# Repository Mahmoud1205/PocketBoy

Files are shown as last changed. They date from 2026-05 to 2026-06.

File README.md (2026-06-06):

# PocketBoy

The PocketBoy is a small handheld console made completely from scratch with a custom PCB and enclosure. The PocketBoy is small enough to fit in a pocket but has a 1000mAh battery for long gaming sessions. The PocketBoy has 8 buttons and a 128x64 monochrome OLED display, it also has a buzzer and a vibration motor.

The PocketBoy is made so you can kill time offline anywhere you are. It is very small (approximately 8x5cm) to easily fit in a pocket and has a strong battery which can be easily replaced. It also has a passive buzzer and vibration motor for extra immersion.

This is a project for the Hack Club Fallout program.

## How to use the PocketBoy

## Fabrication and Assembly Info
- Design files can be found in `/Design/Hardware`.
- Shapr3D link: https://app.shapr3d.com/p/6ae6ebff-efae-4364-8fd7-c0a60253d18e
- Some prototype code can be found in `/Design/Software`. More software will be added in the future.
- M2x20mm screws are used to hold the two enclosure parts together. Please thread them manually after printing the enclosure.
- Please ensure to solder the USB connector accurately so it can fit in the enclosure.
- Please print the design so that the two enclosure parts and all of the buttons are separate from each other.
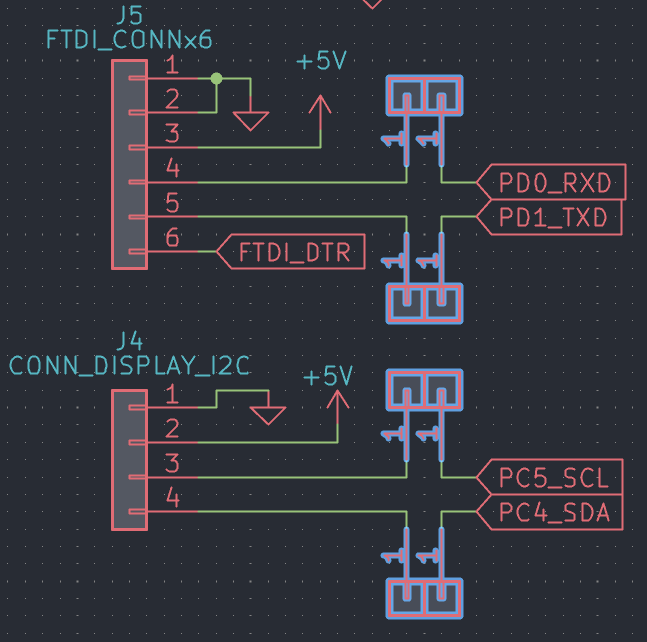
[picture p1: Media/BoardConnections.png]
Board Connections
- The PCB is split into two PCBs, they are connected together using wires after printing both of them. The board connection wires are drawn in the schematic as two 01x01 connectors placed next to each other as in the image below. 
- When soldering the power switch on the bottom PCB, please make sure that its wires come out of the top PCB so the switch can be placed in its position securely.
- After all parts are fabricated, you assemble the console this way: first place the battery at the bottom of the enclosure, then place the bottom PCB above the battery, it should float above the battery because the USB connecter will raise it. Then put the power switch in its hole and secure it in its place. Then place the buttons on the top part of the enclosure and then align the top PCB to be placed above the bottom PCB with a distance enough to keep the buttons stable above the top PCB. Then put the display in the display hole on the top part of the enclosure. Then place both parts of the enclosure on top of each other and hold them together using M2x20mm screws.
- The board can be programmed using an FTDI connector on the top PCB.

## Notes for Fallout reviewers.
As of now there is only a very simple FlappyBird game but I will make more games when the console is built.

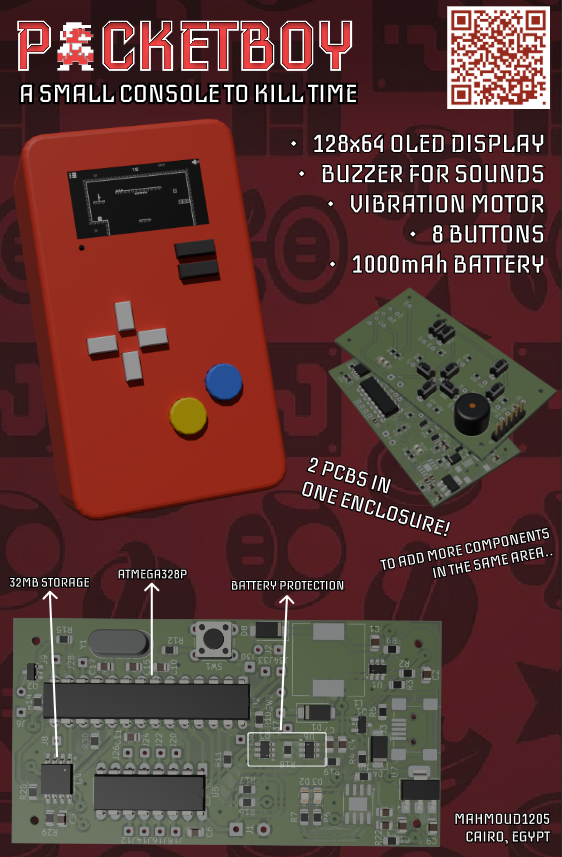
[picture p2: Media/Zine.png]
Zine

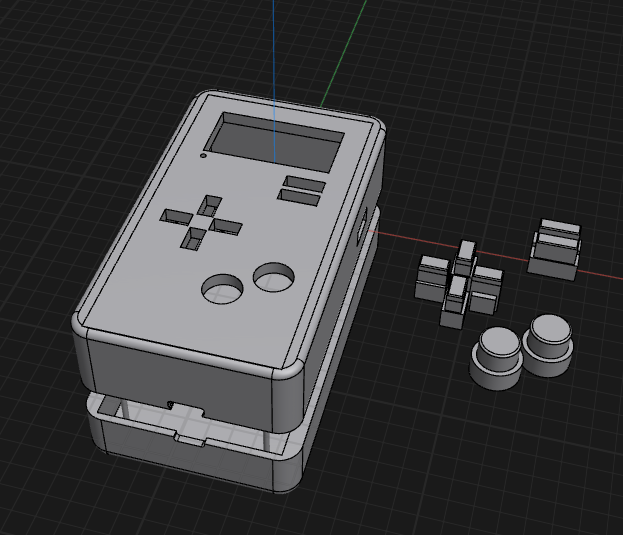
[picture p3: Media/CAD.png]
CAD

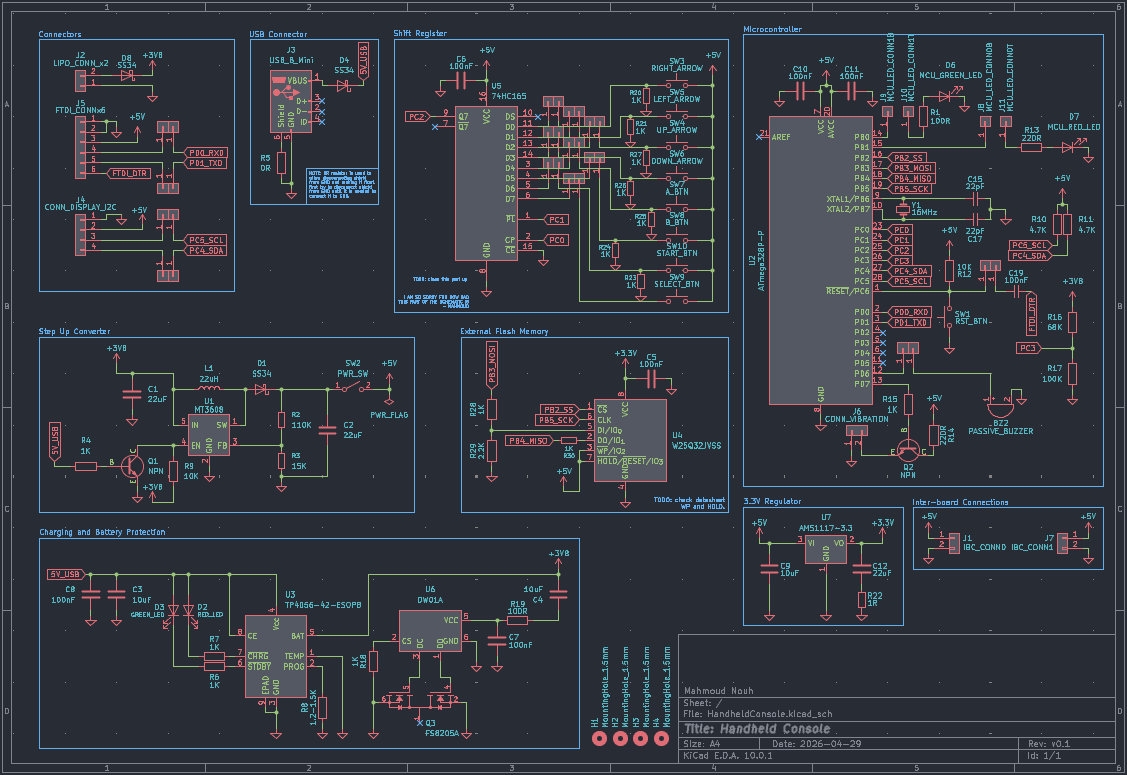
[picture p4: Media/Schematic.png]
Schematic

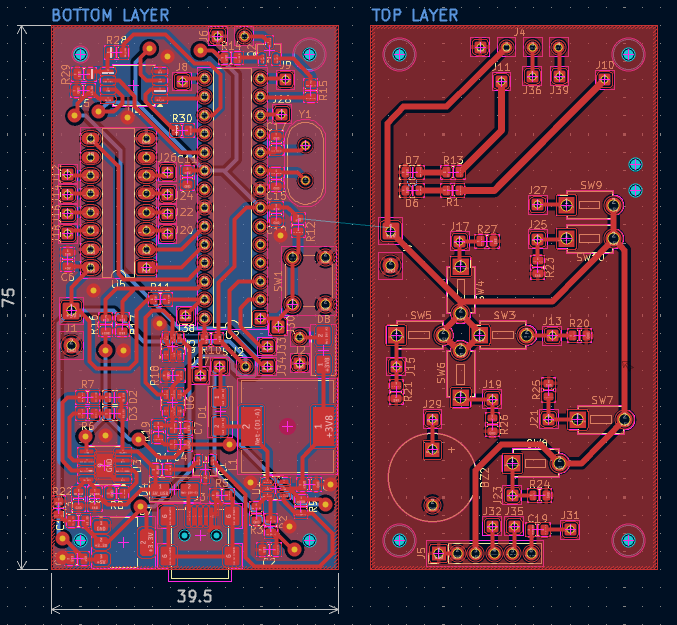
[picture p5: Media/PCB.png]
PCB


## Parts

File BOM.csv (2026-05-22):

 | Sourced | Placed | References | Value | Footprint | Quantity | Link
1 |  |  | C5, C6, C7, C8, C10, C11, C19 | 100nF | C_0805_2012Metric | 7 | https://lampatronics.com/product/smd-multilayer-ceramic-capacitor-0805-2012-104-100nf-50v-1pcs-2
2 |  |  | C1, C2, C12 | 22uF | C_0805_2012Metric | 3 | https://lampatronics.com/product/smd-multilayer-ceramic-capacitor-0805-22uf-6-3v-1pcs
3 |  |  | C3, C4, C9 | 10uF | C_0805_2012Metric | 3 | https://lampatronics.com/product/smd-multilayer-ceramic-capacitor-0805-10610uf-16v-1pcs
4 |  |  | C15, C17 | 22pF | C_0805_2012Metric | 2 | https://lampatronics.com/product/smd-multilayer-ceramic-capacitor-0805-2012-104-100nf-50v-1pcs
5 |  |  | R4, R6, R7, R15, R18, R20, R21, R23, R24, R25, R26, R27, R28, R30 | 1K | R_0805_2012Metric | 14 | https://lampatronics.com/product/smd-resistor-1kohm-102-0805-10pcs
6 |  |  | R1, R19 | 100R | R_0805_2012Metric | 2 | https://lampatronics.com/product/smd-resistor-100ohm-101-0805-10pcs
7 |  |  | R9, R12 | 10K | R_0805_2012Metric | 2 | https://lampatronics.com/product/smd-resistor-10kohm-103-0805-10pcs
8 |  |  | R10, R11 | 4.7K | R_0805_2012Metric | 2 | https://lampatronics.com/product/smd-resistor-4-7kohm-472-0805-10pcs
9 |  |  | R13, R14 | 220R | R_0805_2012Metric | 2 | https://lampatronics.com/product/smd-resistor-220ohm-221-0805-10pcs
10 |  |  | R2 | 110K | R_0805_2012Metric | 1 | https://makerselectronics.com/product/chip-resistor-smd-110k%cf%89-%c2%b11-0-125w-%c2%b1100ppm-%e2%84%83-0805/
11 |  |  | R3 | 15K | R_0805_2012Metric | 1 | https://makerselectronics.com/product/chip-resistor-smd-15k%CF%89-%C2%B11-0-125w-%C2%B1100ppm-%E2%84%83-0805/
12 |  |  | R5 | 0R | R_0805_2012Metric | 1 | https://makerselectronics.com/product/chip-resistor-smd-0%CF%89-%C2%B11-0-125w-0805/
13 |  |  | R8 | 1.2-1.5K | R_0805_2012Metric | 1 | https://lampatronics.com/product/smd-resistor-1-2kohm-122-0805-10pcs
14 |  |  | R16 | 68K | R_0805_2012Metric | 1 | https://makerselectronics.com/product/chip-resistor-smd-68k%CF%89-%C2%B11-0-125w-%C2%B1100ppm-%E2%84%83-0805/
15 |  |  | R17 | 100K | R_0805_2012Metric | 1 | https://lampatronics.com/product/smd-resistor-100kohm-104-0805-10pcs
16 |  |  | R22 | 1R | R_0805_2012Metric | 1 | https://lampatronics.com/product/smd-resistor-1ohm-1r0-0805-10pcs
17 |  |  | R29 | 2.2K | R_0805_2012Metric | 1 | https://lampatronics.com/product/smd-resistor-2-2kohm-222-0805-10pcs
18 |  |  | L1 | 22uH | L_12x12mm_H4.5mm | 1 | https://makerselectronics.com/product/cdrh124-smd-pwr-fixed-inductors-22u/
19 |  |  | D1, D4, D8 | SS34 | D_SMA | 3 | https://lampatronics.com/product/smd-schottky-diode-ss34-1n5822-3a-40v
20 |  |  | D2 | RED_LED | LED_0805_2012Metric | 1 | https://lampatronics.com/product/smd-led-0805-red-10pcs
21 |  |  | D3 | GREEN_LED | LED_0805_2012Metric | 1 | https://lampatronics.com/product/smd-led-0805-green-10pcs
22 |  |  | D6 | MCU_GREEN_LED | LED_0805_2012Metric | 1 | https://lampatronics.com/product/smd-led-0805-green-10pcs
23 |  |  | D7 | MCU_RED_LED | LED_0805_2012Metric | 1 | https://lampatronics.com/product/smd-led-0805-red-10pcs
24 |  |  | U1 | MT3608 | SOT-23-6 | 1 | https://makerselectronics.com/product/mt3608-boost-converter-type-28v-2v24v-sot-23-6-dc-dc-converter/
25 |  |  | U2 | ATmega328P-P | DIP-28_W7.62mm | 1 | https://lampatronics.com/product/atmega328-p-au-smd
26 |  |  | U3 | TP4056-42-ESOP8 | SOIC-8-1EP_3.9x4.9mm_P1.27mm_EP2.41x3.3mm | 1 | https://makerselectronics.com/product/smd-tp4056-battery-management-sop-8/
27 |  |  | U4 | W25Q32JVSS | SOIC-8_5.3x5.3mm_P1.27mm | 1 | https://makerselectronics.com/product/25q32-flash-memory-32mbit-4mb-soic-8-smd/
28 |  |  | U5 | 74HC165 | DIP-16_W7.62mm_LongPads | 1 | https://free-electronic.com/product/74165-sn74hc165n/
29 |  |  | U6 | DW01A | SOT-23-6 | 1 | https://makerselectronics.com/product/dw01a-sot-23-6-battery-management-smd-ic/
30 |  |  | U7 | AMS1117-3.3 | SOT-223-3_TabPin2 | 1 | https://lampatronics.com/product/ams1117-33v-sot-223-33v-linear-voltage-regulator
31 |  |  | Y1 | 16MHz | Crystal_HC49-4H_Vertical | 1 | https://lampatronics.com/product/crystal-oscillator-16mhz
32 |  |  | SW1 | RST_BTN | SW_PUSH_6mm_H4.3mm | 1 | https://lampatronics.com/product/push-button-4pin-6x6x5mm
33 |  |  | SW2 | PWR_SW | SolderWire-0.1sqmm_1x02_P3.6mm_D0.4mm_OD1mm | 1 | https://makerselectronics.com/product/slide-switch-on-off-panel-mount-2-po/
34 |  |  | SW3 | RIGHT_ARROW | SW_PUSH_1P1T_6x3.5mm_H5.0_APEM_MJTP1250 | 1 | https://makerselectronics.com/product/push-button-3x6x5-0mm-dip-2-pin-blac/
35 |  |  | SW4 | UP_ARROW | SW_PUSH_1P1T_6x3.5mm_H5.0_APEM_MJTP1250 | 1 | https://makerselectronics.com/product/push-button-3x6x5-0mm-dip-2-pin-blac/
36 |  |  | SW5 | LEFT_ARROW | SW_PUSH_1P1T_6x3.5mm_H5.0_APEM_MJTP1250 | 1 | https://makerselectronics.com/product/push-button-3x6x5-0mm-dip-2-pin-blac/
37 |  |  | SW6 | DOWN_ARROW | SW_PUSH_1P1T_6x3.5mm_H5.0_APEM_MJTP1250 | 1 | https://makerselectronics.com/product/push-button-3x6x5-0mm-dip-2-pin-blac/
38 |  |  | SW7 | A_BTN | SW_PUSH_1P1T_6x3.5mm_H5.0_APEM_MJTP1250 | 1 | https://makerselectronics.com/product/push-button-3x6x5-0mm-dip-2-pin-blac/
39 |  |  | SW8 | B_BTN | SW_PUSH_1P1T_6x3.5mm_H5.0_APEM_MJTP1250 | 1 | https://makerselectronics.com/product/push-button-3x6x5-0mm-dip-2-pin-blac/
40 |  |  | SW9 | SELECT_BTN | SW_PUSH_1P1T_6x3.5mm_H5.0_APEM_MJTP1250 | 1 | https://makerselectronics.com/product/push-button-3x6x5-0mm-dip-2-pin-blac/
41 |  |  | SW10 | START_BTN | SW_PUSH_1P1T_6x3.5mm_H5.0_APEM_MJTP1250 | 1 | https://makerselectronics.com/product/push-button-3x6x5-0mm-dip-2-pin-blac/
42 |  |  | Q1, Q2 | 2N2222 | SOT-23-3 | 2 | https://lampatronics.com/product/2n2222-1p-mmbt2222a-40-v-600-ma-npn-smd-transistors-sot-23
43 |  |  | BZ2 | PASSIVE_BUZZER | Buzzer_12x9.5RM7.6 | 1 | https://makerselectronics.com/product/passive-buzzer-5v-42%cf%892048hz-12x8-5mm/
44 |  |  | Q3 | FS8205A | SOT-23-6 | 1 | https://makerselectronics.com/product/fs8205a-20v-6a-18m%cf%894-5v6a-1-5w-2-n-channel-sot-23-6-mosfet-smd/
45 |  |  | J12, J13, J14, J15, J16, J17, J18, J19, J20, J21, J22, J23, J24, J25, J26, J27, J28, J29, J30, J31, J32, J33, J34, J35, J36, J37, J38, J39 | BOTTOM | SolderWire-0.1sqmm_1x01_D0.4mm_OD1mm | 28 | https://makerselectronics.com/product/30-awg-wrapping-wire-0-25mm/
46 |  |  | J1 | IBC_CONN0 | SolderWire-0.5sqmm_1x02_P4.8mm_D0.9mm_OD2.3mm | 1 | https://makerselectronics.com/product/30-awg-wrapping-wire-0-25mm/
47 |  |  | J2 | LIPO_CONN_x2 | SolderWire-0.1sqmm_1x02_P3.6mm_D0.4mm_OD1mm | 1 | https://lampatronics.com/product/battery-polymer-3-7v-1000mah-li-ion-single-cell-50x34x5mm-503450
48 |  |  | J3 | USB_B_Mini | USB_Mini-B_Wuerth_65100516121_Horizontal | 1 | https://makerselectronics.com/product/smd-mini-usb-connector-solder-female-5-pin/
49 |  |  | J4 | CONN_DISPLAY_I2C | SolderWire-0.1sqmm_1x04_P3.6mm_D0.4mm_OD1mm | 1 | https://lampatronics.com/product/oled-lcd-led-display-module-white-128x64-096-inch
50 |  |  | J5 | FTDI_CONNx6 | PinHeader_1x06_P2.54mm_Vertical | 1 | https://makerselectronics.com/product/pin-headers-male-2-54mm-40-pin-straight-black-11mm/
51 |  |  | J6 | CONN_VIBRATION | SolderWire-0.1sqmm_1x02_P3.6mm_D0.4mm_OD1mm | 1 | https://free-electronic.com/product/mini-vibration-motor/
52 |  |  | J7 | IBC_CONN1 | SolderWire-0.5sqmm_1x02_P4.8mm_D0.9mm_OD2.3mm | 1 | https://makerselectronics.com/product/30-awg-wrapping-wire-0-25mm/
53 |  |  | J8 | MCU_LED_CONN0B | SolderWire-0.1sqmm_1x01_D0.4mm_OD1mm | 1 | https://makerselectronics.com/product/30-awg-wrapping-wire-0-25mm/
54 |  |  | J9 | MCU_LED_CONN1B | SolderWire-0.1sqmm_1x01_D0.4mm_OD1mm | 1 | https://makerselectronics.com/product/30-awg-wrapping-wire-0-25mm/
55 |  |  | J10 | MCU_LED_CONN1T | SolderWire-0.1sqmm_1x01_D0.4mm_OD1mm | 1 | https://makerselectronics.com/product/30-awg-wrapping-wire-0-25mm/
56 |  |  | J11 | MCU_LED_CONN0T | SolderWire-0.1sqmm_1x01_D0.4mm_OD1mm | 1 | https://makerselectronics.com/product/30-awg-wrapping-wire-0-25mm/

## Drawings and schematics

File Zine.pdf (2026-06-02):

# P CKETBOY

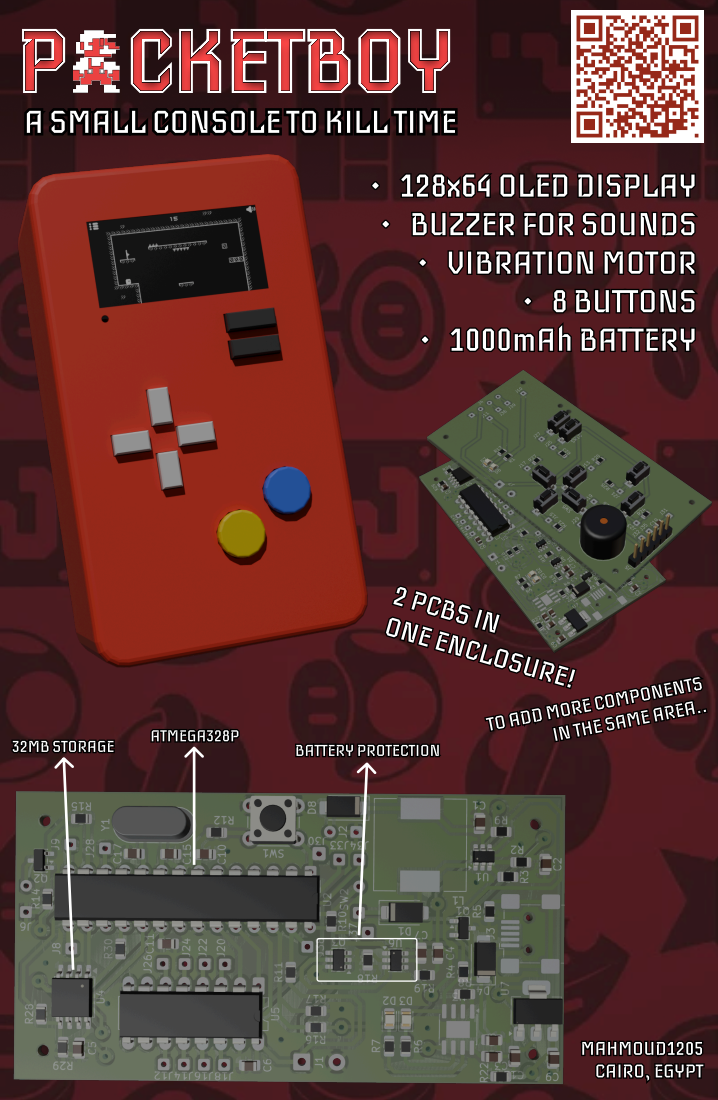
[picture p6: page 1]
8 BUTTONS 1000mAh BATTERY; 32MB STORAGE; ATMEGA328P; TO ADD MORE COMPONENTS; BATTERY PROTECTION; 2 PCBS IN ONE ENCLOSURE!; MAHMOUD1205; CAIRO, EGYPT

A SMALL CONSOLE TO KILL TIME

128x64 OLED DISPLAY
BUZZER FOR SOUNDS
VIBRATION MOTOR

IN THE SAME AREA..

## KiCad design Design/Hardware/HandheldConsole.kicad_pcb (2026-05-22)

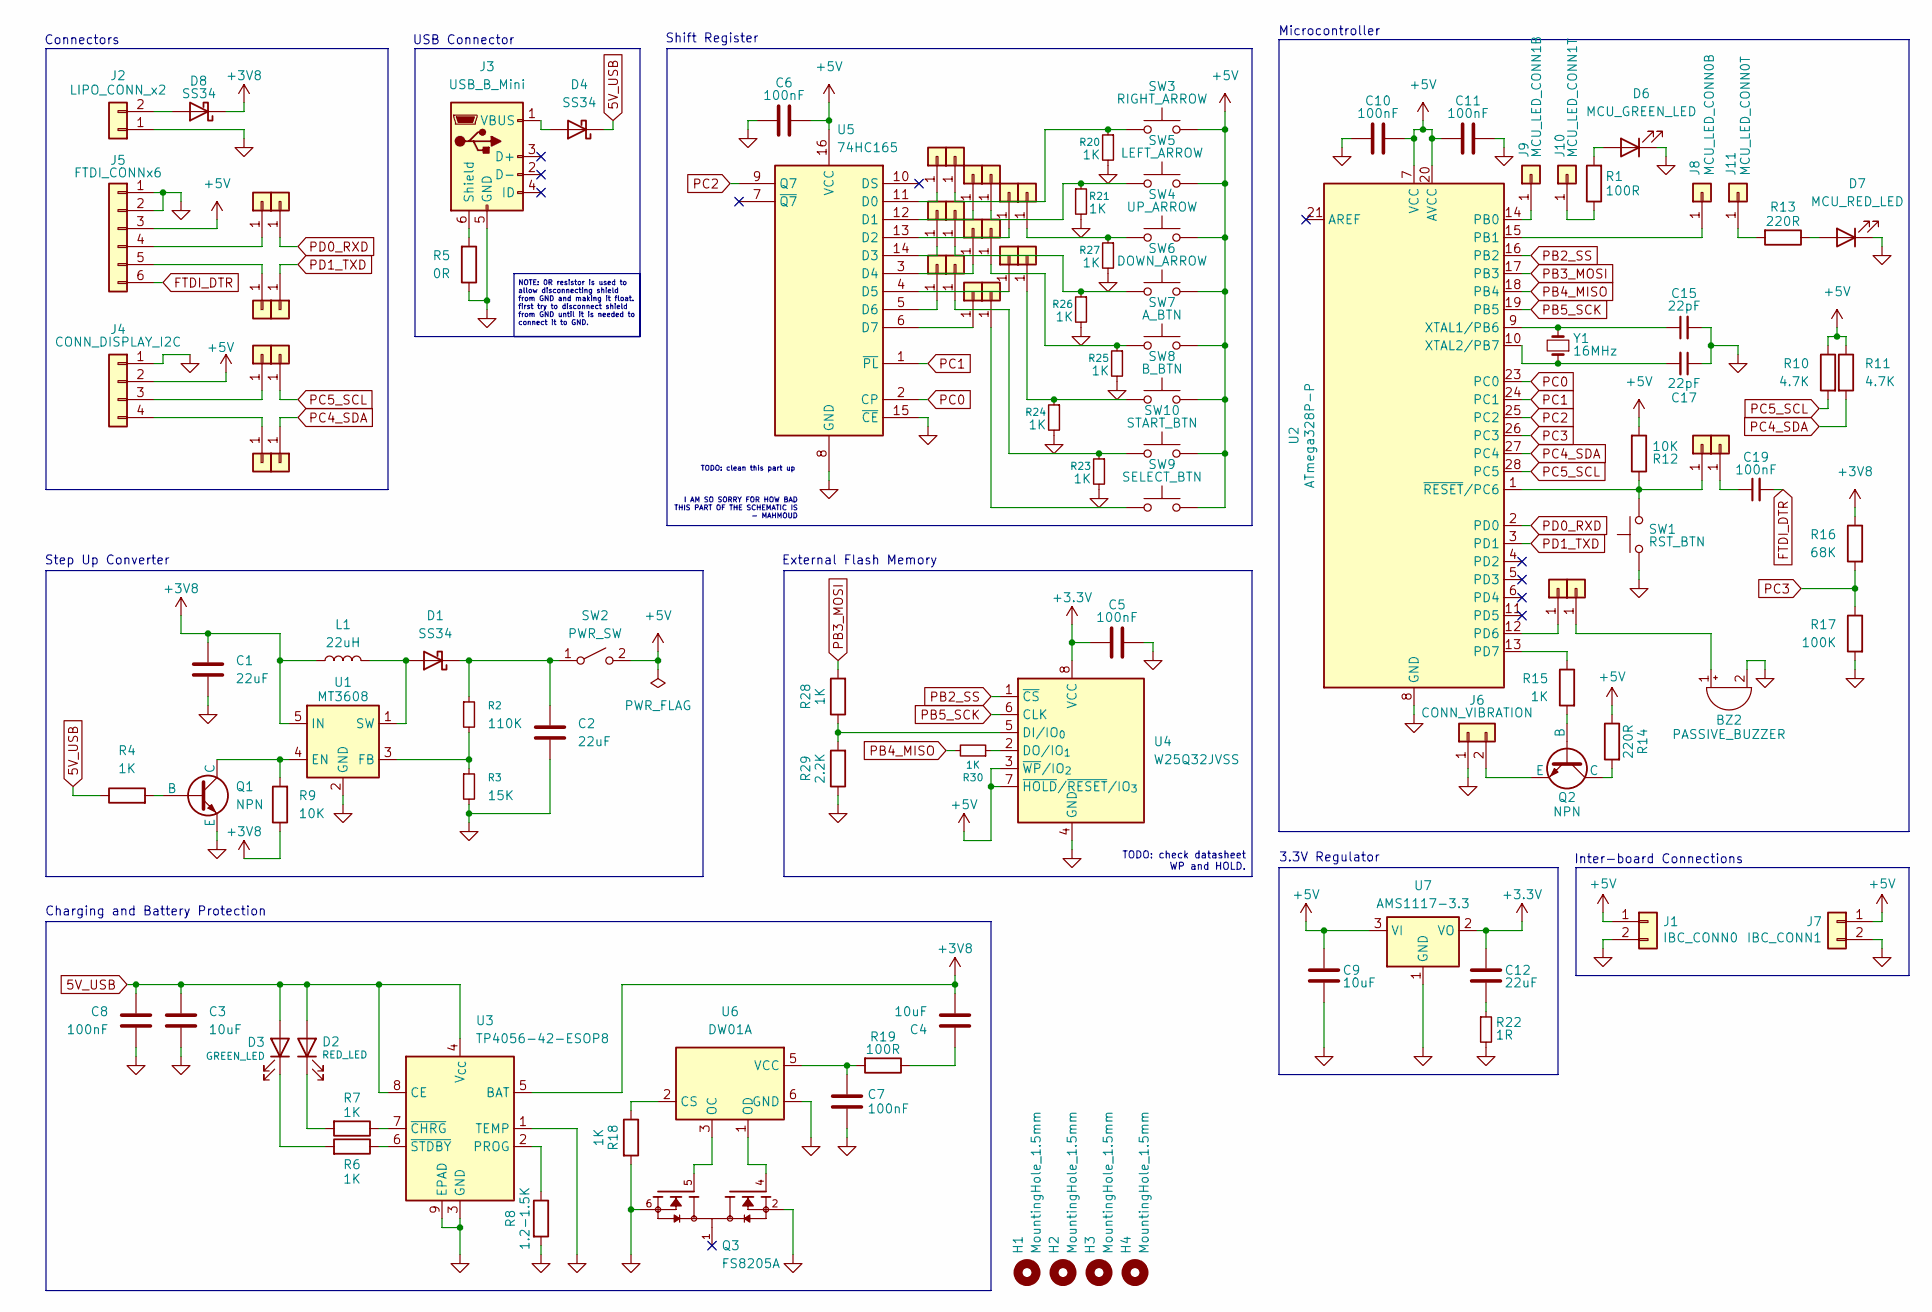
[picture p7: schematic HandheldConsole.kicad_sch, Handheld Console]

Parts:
BZ2: PASSIVE_BUZZER; Buzzer_12x9.5RM7.6
C1, C2, C12: 22uF; C_0805_2012Metric
C3, C4, C9: 10uF; C_0805_2012Metric
C5, C6, C7, C8, C10, C11, C19: 100nF; C_0805_2012Metric
C15, C17: 22pF; C_0805_2012Metric
D1, D4, D8: SS34; D_SMA
D2: RED_LED; LED_0805_2012Metric
D3: GREEN_LED; LED_0805_2012Metric
D6: MCU_GREEN_LED; LED_0805_2012Metric
D7: MCU_RED_LED; LED_0805_2012Metric
H1, H2, H3, H4: MountingHole_1.5mm; MountingHole_2.1mm
J1: IBC_CONN0; SolderWire-0.5sqmm_1x02_P4.8mm_D0.9mm_OD2.3mm
J2: LIPO_CONN_x2; SolderWire-0.1sqmm_1x02_P3.6mm_D0.4mm_OD1mm
J3: USB_B_Mini; USB_Mini-B_Wuerth_65100516121_Horizontal
J4: CONN_DISPLAY_I2C; SolderWire-0.1sqmm_1x04_P3.6mm_D0.4mm_OD1mm
J5: FTDI_CONNx6; PinHeader_1x06_P2.54mm_Vertical
J6: CONN_VIBRATION; SolderWire-0.1sqmm_1x02_P3.6mm_D0.4mm_OD1mm
J7: IBC_CONN1; SolderWire-0.5sqmm_1x02_P4.8mm_D0.9mm_OD2.3mm
J8: MCU_LED_CONN0B; SolderWire-0.1sqmm_1x01_D0.4mm_OD1mm
J9: MCU_LED_CONN1B; SolderWire-0.1sqmm_1x01_D0.4mm_OD1mm
J10: MCU_LED_CONN1T; SolderWire-0.1sqmm_1x01_D0.4mm_OD1mm
J11: MCU_LED_CONN0T; SolderWire-0.1sqmm_1x01_D0.4mm_OD1mm
J12, J13, J14, J15, J16, J17, J18, J19, J20, J21, J22, J23, J24, J25, J26, J27, J28, J29, J30, J31, J32, J33, J34, J35, J36, J37, J38, J39: BOTTOM; SolderWire-0.1sqmm_1x01_D0.4mm_OD1mm
L1: 22uH; L_12x12mm_H4.5mm
Q1, Q2: NPN; SOT-23-3
Q3: FS8205A; SOT-23-6; PARTREV 1.7
R1, R19: 100R; R_0805_2012Metric
R2: 110K; R_0805_2012Metric
R3: 15K; R_0805_2012Metric
R4, R6, R7, R15, R18, R20, R21, R23, R24, R25, R26, R27, R28, R30: 1K; R_0805_2012Metric
R5: 0R; R_0805_2012Metric
R8: 1.2-1.5K; R_0805_2012Metric
R9, R12: 10K; R_0805_2012Metric
R10, R11: 4.7K; R_0805_2012Metric
R13, R14: 220R; R_0805_2012Metric
R16: 68K; R_0805_2012Metric
R17: 100K; R_0805_2012Metric
R22: 1R; R_0805_2012Metric
R29: 2.2K; R_0805_2012Metric
SW1: RST_BTN; SW_PUSH_6mm_H4.3mm
SW2: PWR_SW; SolderWire-0.1sqmm_1x02_P3.6mm_D0.4mm_OD1mm
SW3: RIGHT_ARROW; SW_PUSH_1P1T_6x3.5mm_H5.0_APEM_MJTP1250
SW4: UP_ARROW; SW_PUSH_1P1T_6x3.5mm_H5.0_APEM_MJTP1250
SW5: LEFT_ARROW; SW_PUSH_1P1T_6x3.5mm_H5.0_APEM_MJTP1250
SW6: DOWN_ARROW; SW_PUSH_1P1T_6x3.5mm_H5.0_APEM_MJTP1250
SW7: A_BTN; SW_PUSH_1P1T_6x3.5mm_H5.0_APEM_MJTP1250
SW8: B_BTN; SW_PUSH_1P1T_6x3.5mm_H5.0_APEM_MJTP1250
SW9: SELECT_BTN; SW_PUSH_1P1T_6x3.5mm_H5.0_APEM_MJTP1250
SW10: START_BTN; SW_PUSH_1P1T_6x3.5mm_H5.0_APEM_MJTP1250
U1: MT3608; SOT-23-6
U2: ATmega328P-P; DIP-28_W7.62mm
U3: TP4056-42-ESOP8; SOIC-8-1EP_3.9x4.9mm_P1.27mm_EP2.41x3.3mm
U4: W25Q32JVSS; SOIC-8_5.3x5.3mm_P1.27mm
U5: 74HC165; DIP-16_W7.62mm_LongPads
U6: DW01A; SOT-23-6
U7: AMS1117-3.3; SOT-223-3_TabPin2
Y1: 16MHz; Crystal_HC49-4H_Vertical

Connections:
5V_USB: C3.1, C8.1, D2.2 (A), D3.2 (A), D4.1 (K), R4.1, U3.4 (V_{CC}), U3.8 (CE)
+3.3V: C5.2, C12.1, U4.8 (VCC), U7.2 (VO)
+3V8: C1.1, C4.2, D8.1 (K), L1.1, R9.1, R16.1, U1.5 (IN), U3.5 (BAT)
+5V: C6.2, C9.1, C10.2, C11.2, J1.1, J4.2, J5.3, J7.1, R10.1, R11.1, R12.2, R14.1, SW2.2 (B), SW3.1, SW4.2, SW5.2, SW6.2, SW7.2, SW8.2, SW9.2, SW10.2, U2.7 (VCC), U2.20 (AVCC), U4.3 (~WP/IO_{2}), U4.7 (~HOLD/~RESET/IO_{3}), U5.16 (VCC), U7.3 (VI)
FTDI_DTR: C19.2, J5.6
GND: BZ2.2 (-), C1.2, C2.2, C3.2, C5.1, C6.1, C7.2, C8.2, C9.2, C10.1, C11.1, C15.2, C17.1, D6.1 (K), D7.1 (K), J1.2, J2.1, J3.5 (GND), J4.1, J5.1, J5.2, J6.1, J7.2, Q1.3 (E), Q3.2, Q3.3, Q3.6, Q3.7, R3.2, R5.1, R8.2, R17.2, R18.2, R20.2, R21.2, R22.2, R23.2, R24.2, R25.2, R26.2, R27.2, R29.1, SW1.2, U1.2 (GND), U2.8 (GND), U2.22 (GND), U3.1 (TEMP), U3.3 (GND), U3.9 (EPAD), U4.4 (GND), U5.8 (GND), U5.15 (~CE), U6.6 (GND), U7.1 (GND)
unnamed: BZ2.1 (+), J29.1 (Pin_1_1)
unnamed: C4.1, R19.1
unnamed: C12.2, R22.1
unnamed: D1.2 (A), L1.2, U1.1 (SW)
unnamed: C2.1, D1.1 (K), R2.1, SW2.1 (A)
unnamed: D2.1 (K), R7.2
unnamed: D3.1 (K), R6.2
unnamed: D4.2 (A), J3.1 (VBUS)
unnamed: D6.2 (A), R1.2
unnamed: D7.2 (A), R13.1
unnamed: D8.2 (A), J2.2
unnamed: J3.6 (Shield), R5.2
unnamed: J6.2, Q2.3 (E)
unnamed: J8.1 (Pin_1_1), U2.15 (PB1)
unnamed: J9.1 (Pin_1_1), U2.14 (PB0)
unnamed: J10.1 (Pin_1_1), R1.1
unnamed: J11.1 (Pin_1_1), R13.2
unnamed: J12.1 (Pin_1_1), U5.11 (D0)
unnamed: J13.1 (Pin_1_1), R20.1, SW3.2
unnamed: J14.1 (Pin_1_1), U5.12 (D1)
unnamed: J15.1 (Pin_1_1), R21.1, SW5.1
unnamed: J16.1 (Pin_1_1), U5.13 (D2)
unnamed: J17.1 (Pin_1_1), R27.1, SW4.1
unnamed: J18.1 (Pin_1_1), U5.14 (D3)
unnamed: J19.1 (Pin_1_1), R26.1, SW6.1
unnamed: J20.1 (Pin_1_1), U5.3 (D4)
unnamed: J21.1 (Pin_1_1), R25.1, SW7.1
unnamed: J22.1 (Pin_1_1), U5.4 (D5)
unnamed: J23.1 (Pin_1_1), R24.1, SW8.1
unnamed: J24.1 (Pin_1_1), U5.5 (D6)
unnamed: J25.1 (Pin_1_1), R23.1, SW10.1
unnamed: J26.1 (Pin_1_1), U5.6 (D7)
unnamed: J27.1 (Pin_1_1), SW9.1
unnamed: J28.1 (Pin_1_1), U2.12 (PD6)
unnamed: J30.1 (Pin_1_1), R12.1, SW1.1, U2.1 (~RESET/PC6)
unnamed: C19.1, J31.1 (Pin_1_1)
unnamed: J5.4, J32.1 (Pin_1_1)
unnamed: J5.5, J35.1 (Pin_1_1)
unnamed: J4.3, J36.1 (Pin_1_1)
unnamed: J4.4, J39.1 (Pin_1_1)
unnamed: Q1.2 (B), R4.2
unnamed: Q1.1 (C), R9.2, U1.4 (EN)
unnamed: Q2.2 (B), R15.2
unnamed: Q2.1 (C), R14.2
unnamed: R2.2, R3.1, U1.3 (FB)
unnamed: R15.1, U2.13 (PD7)
unnamed: C15.1, U2.9 (XTAL1/PB6), Y1.2
unnamed: C17.2, U2.10 (XTAL2/PB7), Y1.1
unnamed: R8.1, U3.2 (PROG)
unnamed: R7.1, U3.7 (~CHRG)
unnamed: R6.1, U3.6 (~STDBY)
unnamed: R28.1, R29.2, U4.5 (DI/IO_{0})
unnamed: R30.1, U4.2 (DO/IO_{1})
unnamed: R18.1, U6.2 (CS)
unnamed: Q3.5, U6.3 (OC)
unnamed: Q3.4, U6.1 (OD)
unnamed: C7.1, R19.2, U6.5 (VCC)
PB2_SS: U2.16 (PB2), U4.1 (~CS)
PB3_MOSI: R28.2, U2.17 (PB3)
PB4_MISO: R30.2, U2.18 (PB4)
PB5_SCK: U2.19 (PB5), U4.6 (CLK)
PC0: U2.23 (PC0), U5.2 (CP)
PC1: U2.24 (PC1), U5.1 (~PL)
PC2: U2.25 (PC2), U5.9 (Q7)
PC3: R16.2, R17.1, U2.26 (PC3)
PC4_SDA: J38.1 (Pin_1_1), R11.2, U2.27 (PC4)
PC5_SCL: J37.1 (Pin_1_1), R10.2, U2.28 (PC5)
PD0_RXD: J33.1 (Pin_1_1), U2.2 (PD0)
PD1_TXD: J34.1 (Pin_1_1), U2.3 (PD1)

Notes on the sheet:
Step Up Converter
USB Connector
3.3V Regulator
TODO: check datasheet WP and HOLD.
I AM SO SORRY FOR HOW BAD THIS PART OF THE SCHEMATIC IS - MAHMOUD
NOTE: 0R resistor is used to allow disconnecting shield from GND and making it float. first try to disconnect shield from GND until it is needed to connect it to GND.
TODO: clean this part up
Inter-board Connections
Microcontroller
Charging and Battery Protection
Connectors
External Flash Memory
Shift Register

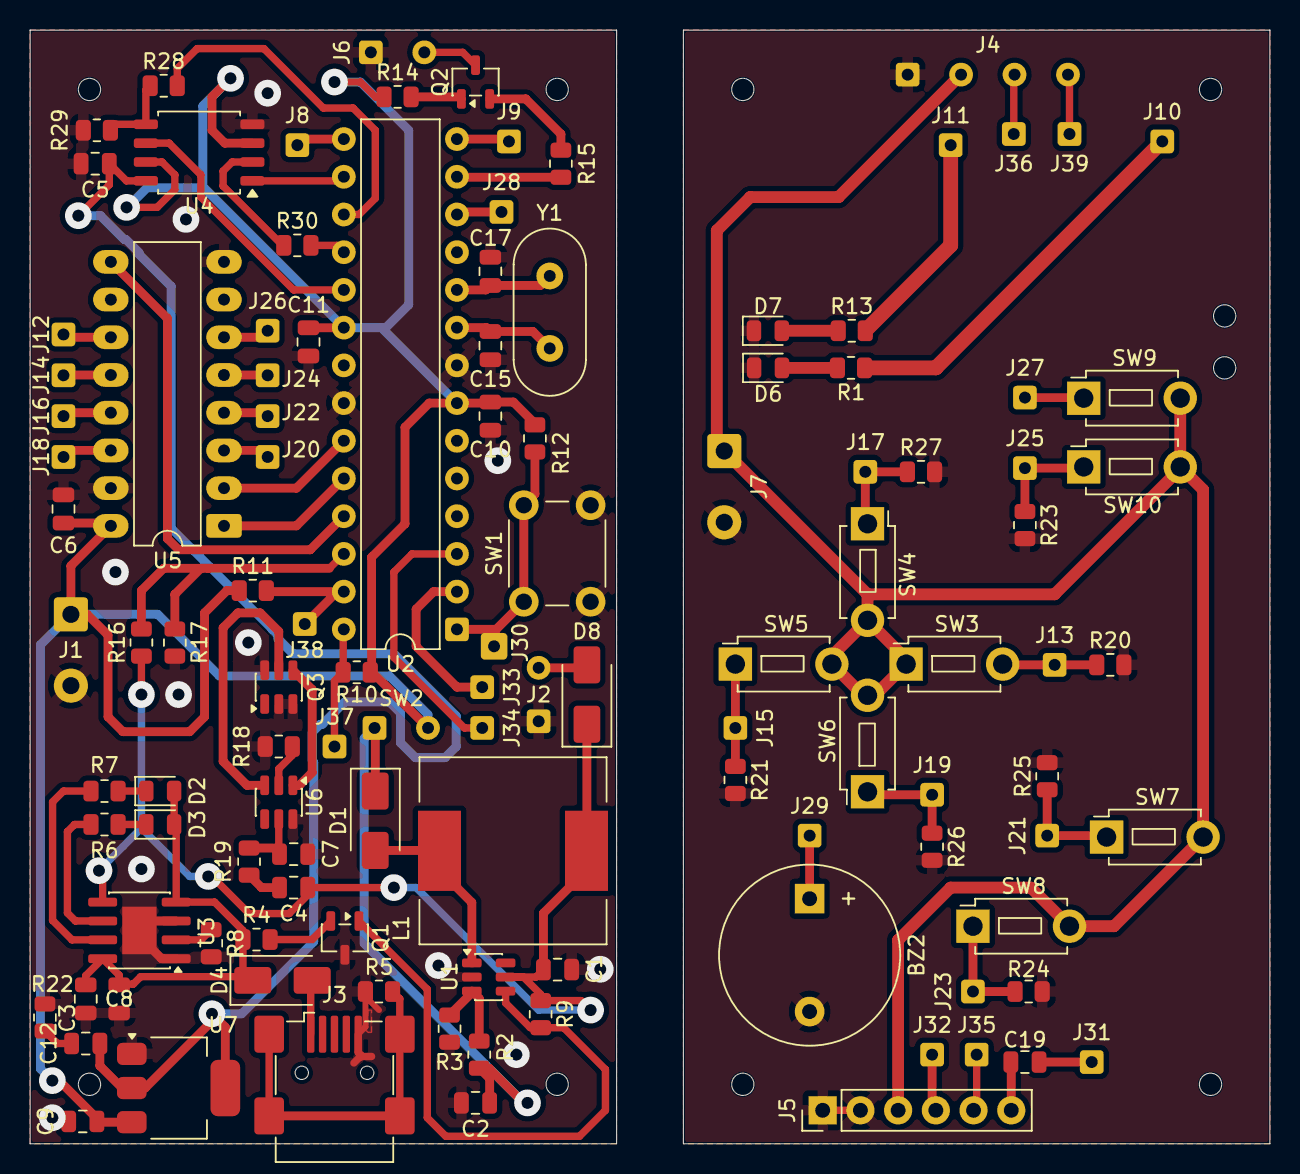
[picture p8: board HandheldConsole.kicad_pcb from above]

Board: 2 copper layers, 83.5 x 75.0 mm, 124 parts (0 on the bottom side), 75 nets.

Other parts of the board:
H1#2, H2#2, H3#2, H3#3, H3#4, H4#2: MountingHole_1.5mm; MountingHole_2.1mm

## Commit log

2026-05-22 add bom
    [BOM.csv]
2026-05-22 finalize repo for fallout
    [HandheldConsole.kicad_pcb, HandheldConsole.kicad_sch]
2026-05-22 add links to bom
    [BOM.csv]
